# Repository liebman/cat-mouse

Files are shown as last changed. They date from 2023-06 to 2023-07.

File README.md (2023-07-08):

# Prototype Rover

Simple autonomous differential drive rover with LIDAR in RUST using an ESP32s3.

- [motor](motor) contains a simple PWM motor control for cheap brushed motors using a phase/enable type motor controller.
- [encoder](encoder) contains a PCNT based quadrature encoder controller to track the position of the encoder.
- [speed-control](speed-control) implements PID control of motor speed using encoder.
- [position-control](position-control) allows the motor position to be controlled by specifying the wanted position in degrees.
- [wheel](wheel) is an abstraction on top of position-control to specify motor position in millimeters.
- [differential-drive](differential-drive) implements rover rotation and forward/reverse movement by specifying the distance or rotation.
- [lidar](lidar) implements LIDAR with an inexpensive LD19 based Lidar like <https://www.amazon.com/dp/B0B1V8D36H>
- [rover](rover) runs around autonomously avoiding things.

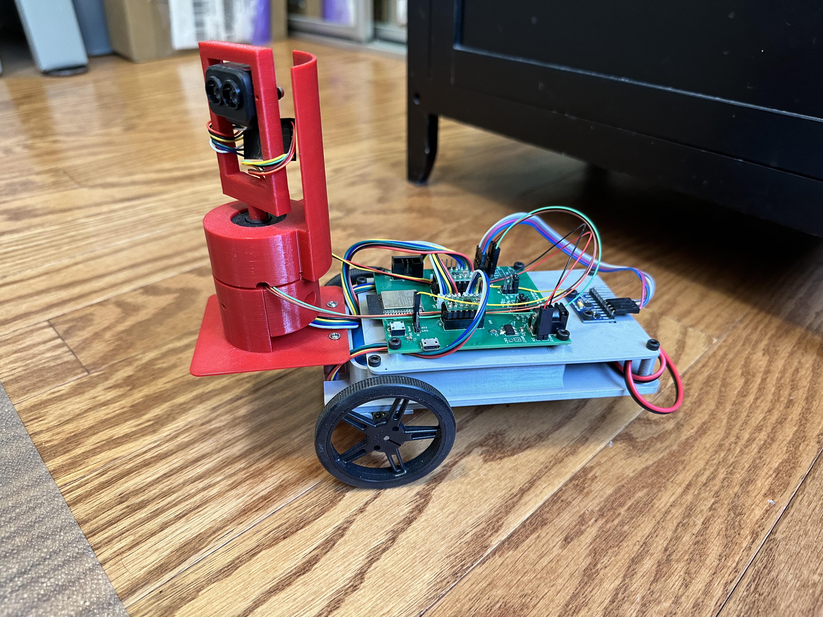
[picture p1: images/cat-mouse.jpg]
Cat Mouse


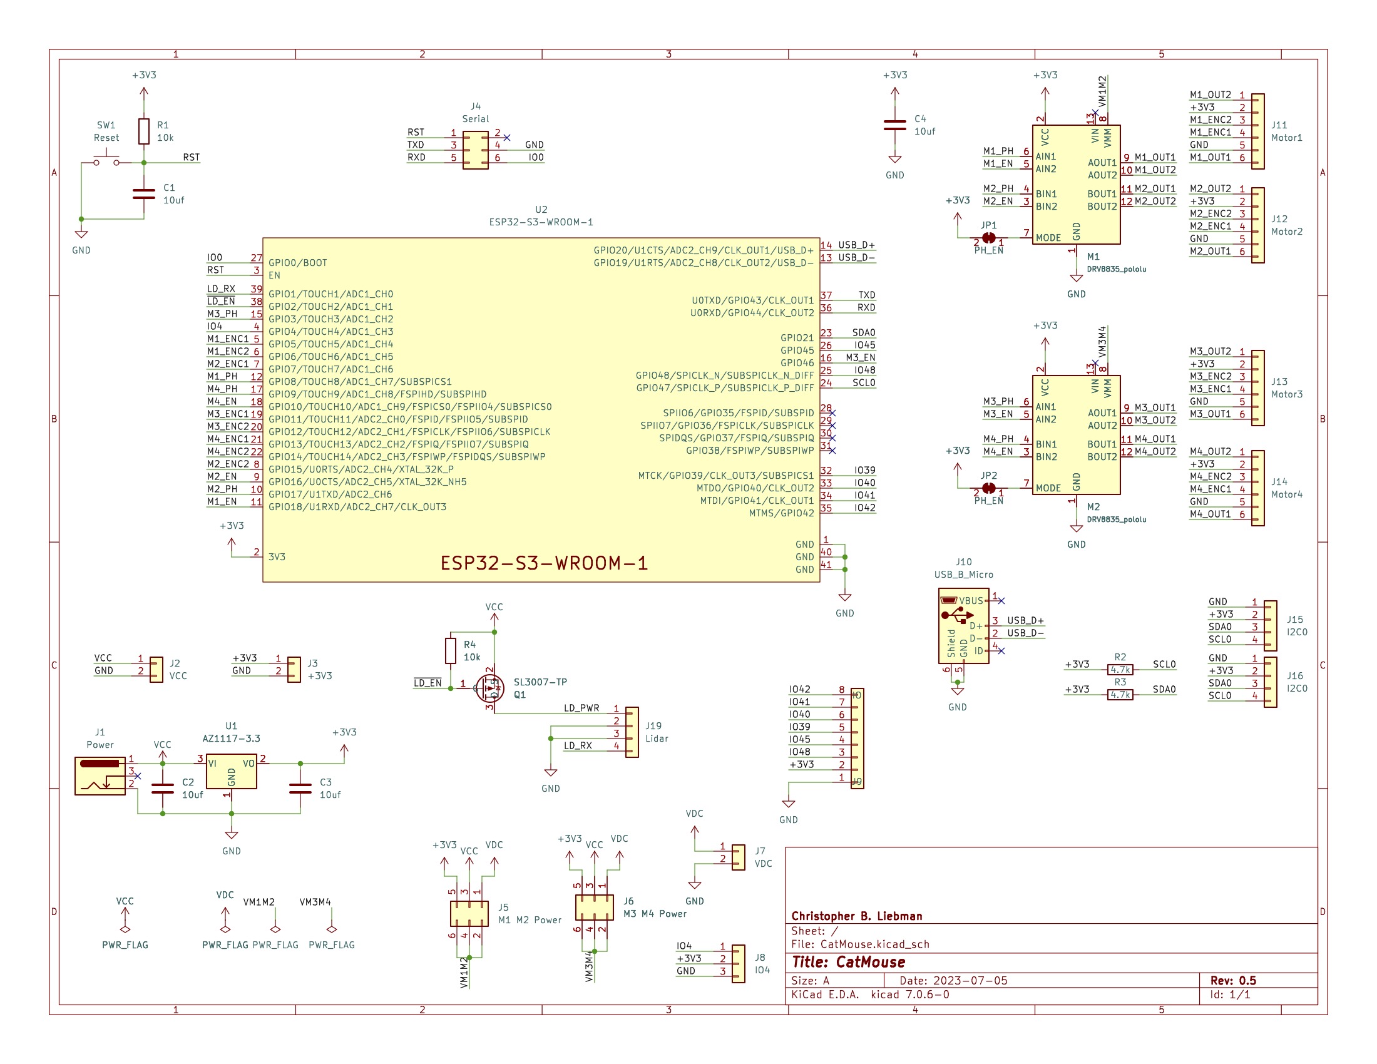
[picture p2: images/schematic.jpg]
Schematic


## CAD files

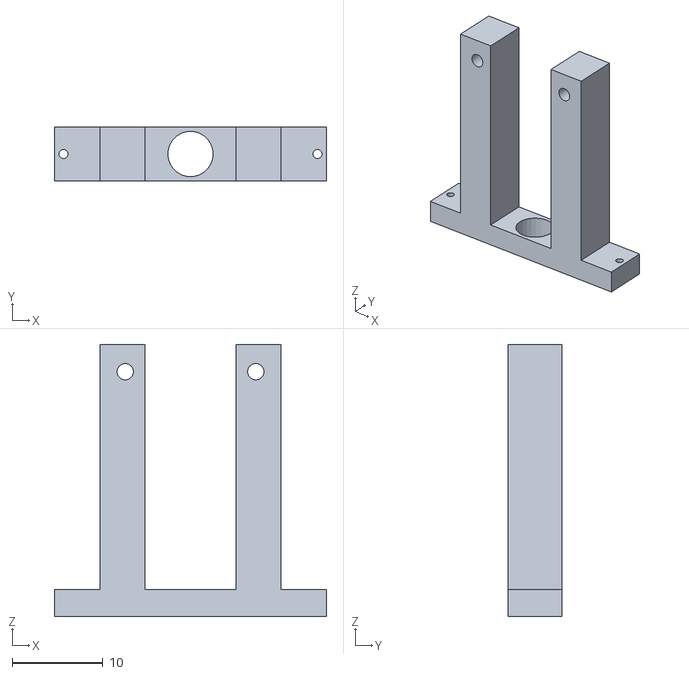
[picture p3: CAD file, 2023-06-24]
hardware/freecad/CatMouse-Lidar.stl
30.0 x 6.00 x 30.0

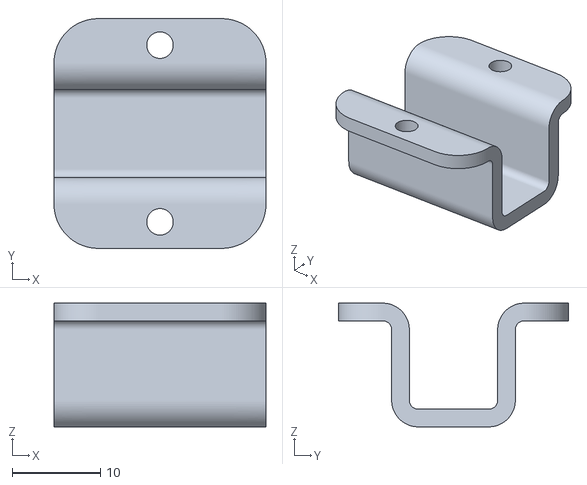
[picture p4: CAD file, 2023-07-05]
hardware/fusion360/N20Mount.stl
24.0 x 26.0 x 14.0

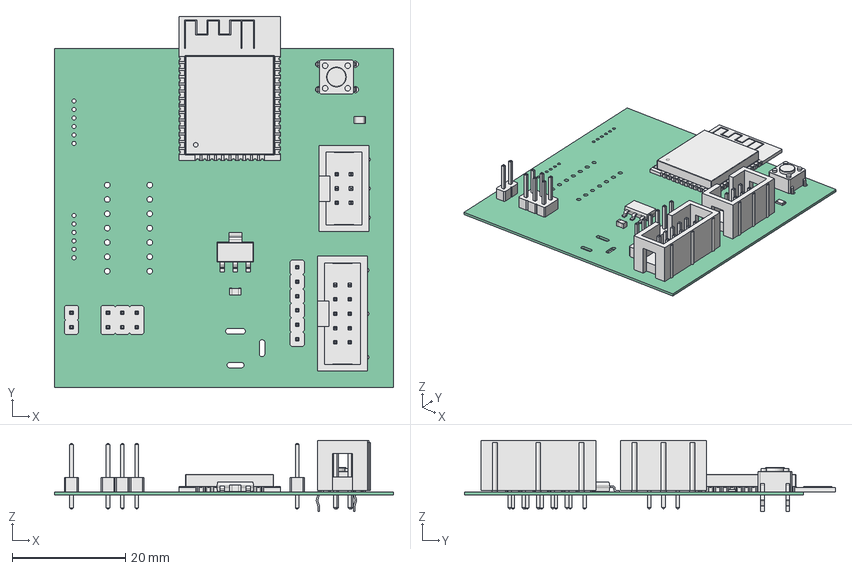
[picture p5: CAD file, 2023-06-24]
hardware/freecad/BoardOutline.FCStd
60.0 x 65.7 x 12.6 mm
Pcb_993c
U2_ESP32-WROOM-32_12fb92eafdae
C1_C_0805_2012Metric_3b40103215d8
R1_R_0805_2012Metric_3ca488a548dd
U1_SOT_223_f805ed2c4214
J3_IDC_Header_2x05_P254mm_Vertical_dc944acc4618
J2_IDC_Header_2x03_P254mm_Vertical_44bb01e61293
J4_PinHeader_2x03_P254mm_Vertical_54f72b17f13c
SW1_SW_PUSH_6mm_3bd36c4098d5
J8_PinHeader_1x06_P254mm_Vertical_c3c84403336c
J5_PinHeader_1x02_P254mm_Vertical_f570ed602196

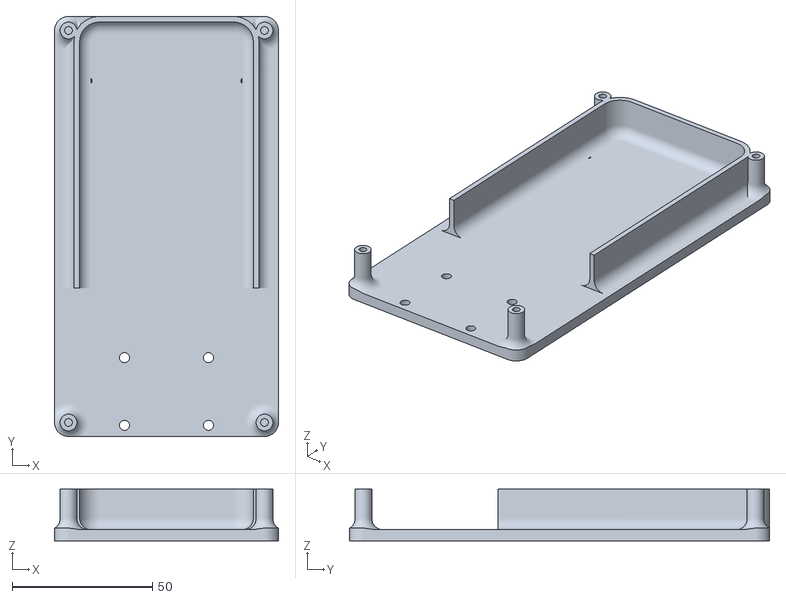
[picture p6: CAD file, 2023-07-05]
hardware/fusion360/Platform.stl
80.0 x 150.0 x 18.5

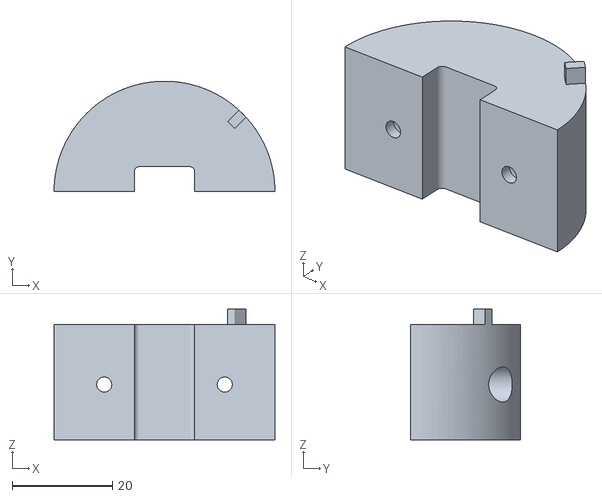
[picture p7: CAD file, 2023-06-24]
hardware/freecad/LIDAR-Front.stl
44.0 x 22.0 x 26.0

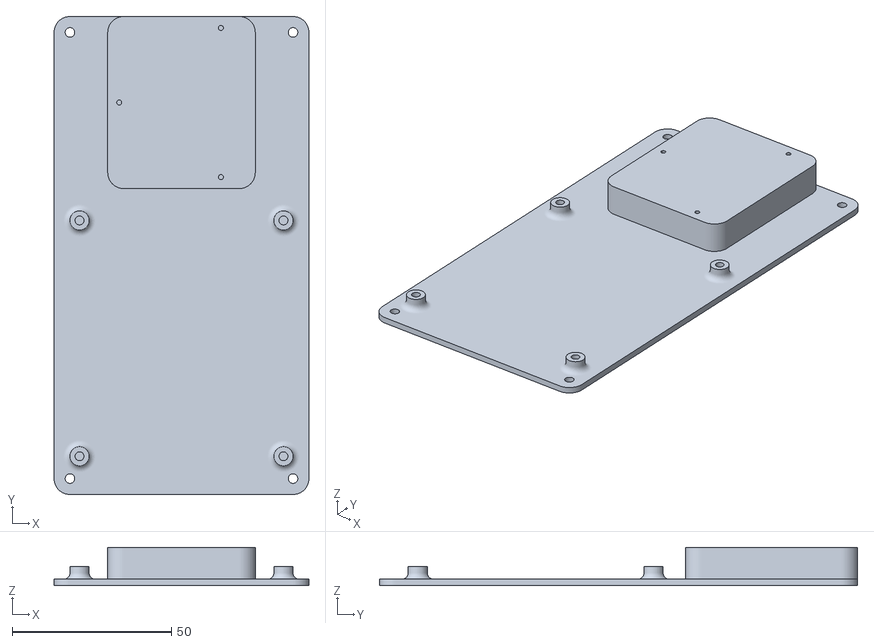
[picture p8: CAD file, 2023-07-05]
hardware/fusion360/BoardMount.stl
80.0 x 150.0 x 12.0

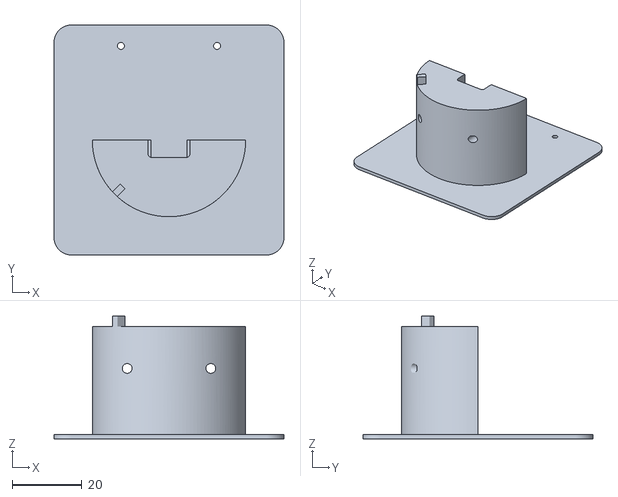
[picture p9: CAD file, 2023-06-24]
hardware/freecad/LIDAR-Back.stl
66.0 x 66.0 x 35.2

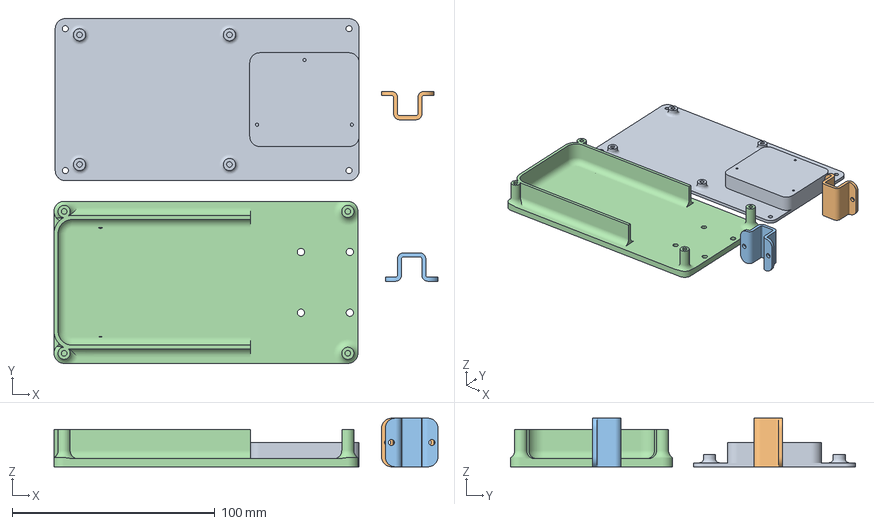
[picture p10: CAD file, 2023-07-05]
hardware/fusion360/cat-mouse.3mf
189.5 x 170.2 x 24.0 mm
BoardMount.stl
N20Mount.stl
Platform.stl

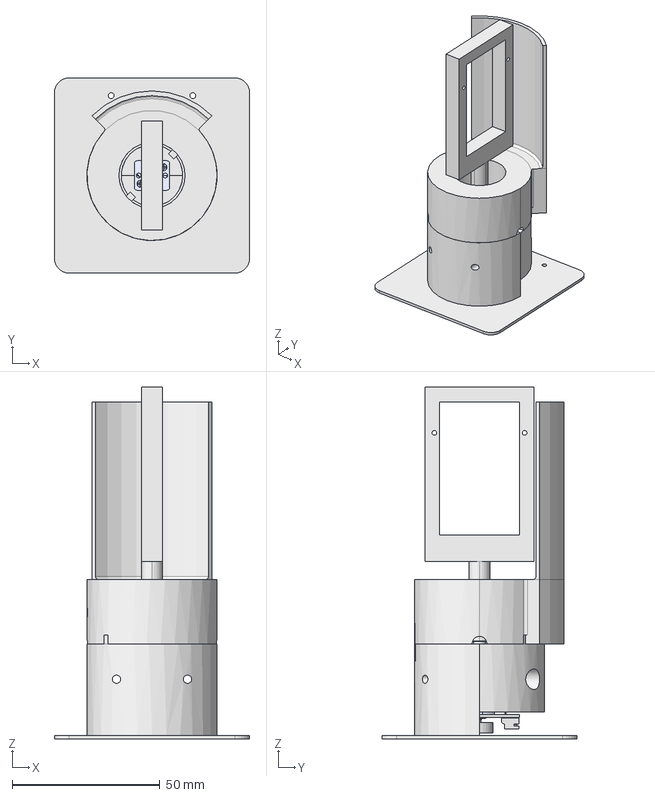
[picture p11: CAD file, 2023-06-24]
hardware/freecad/LIDAR.FCStd
66.0 x 66.0 x 119.0 mm
micro-metal-gearmotor-backshaft v1
S6B-ZR v1
Front
SlipRingTube
Back
TOFMount

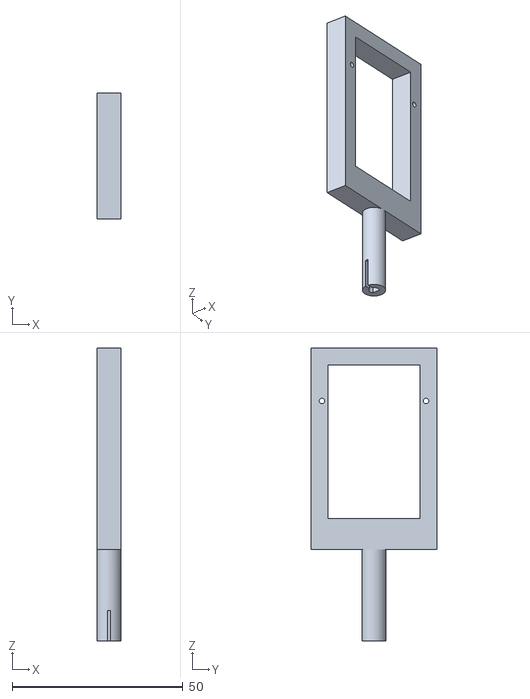
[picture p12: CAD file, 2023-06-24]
hardware/freecad/LIDAR-TOFMount.stl
7.00 x 37.0 x 85.8

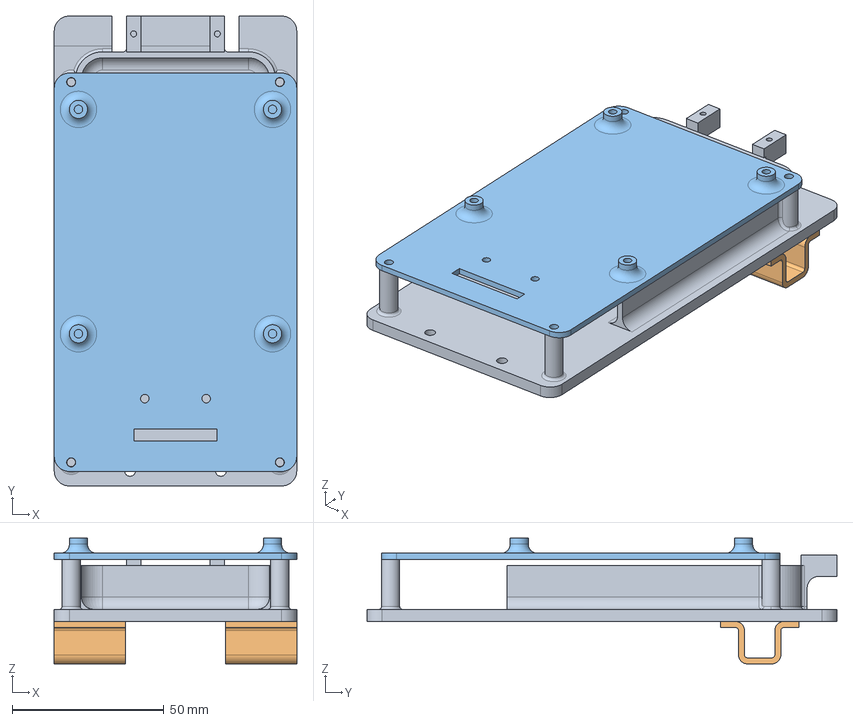
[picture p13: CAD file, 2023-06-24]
hardware/freecad/CatMouse.FCStd
80.0 x 155.0 x 41.5 mm
Platform
N20BracketV x 2
BoardPlatform

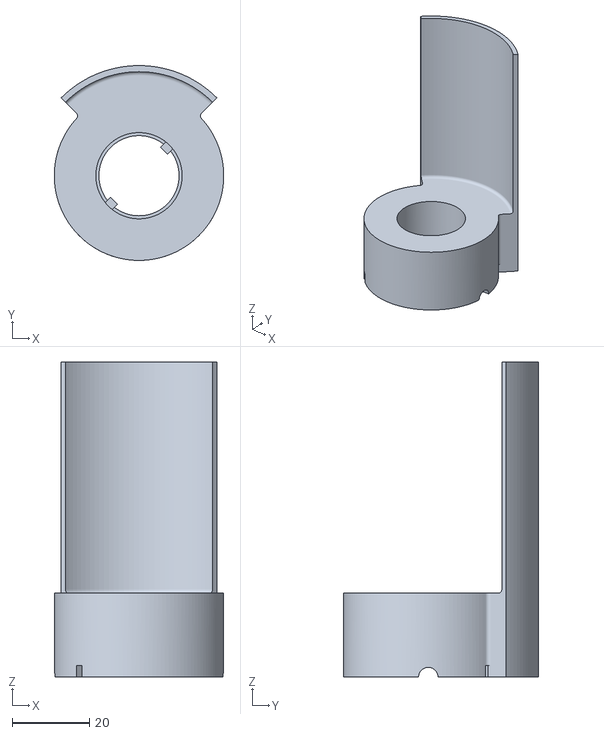
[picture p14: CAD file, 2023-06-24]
hardware/freecad/LIDAR-SlipRingTube.stl
44.0 x 50.6 x 81.8

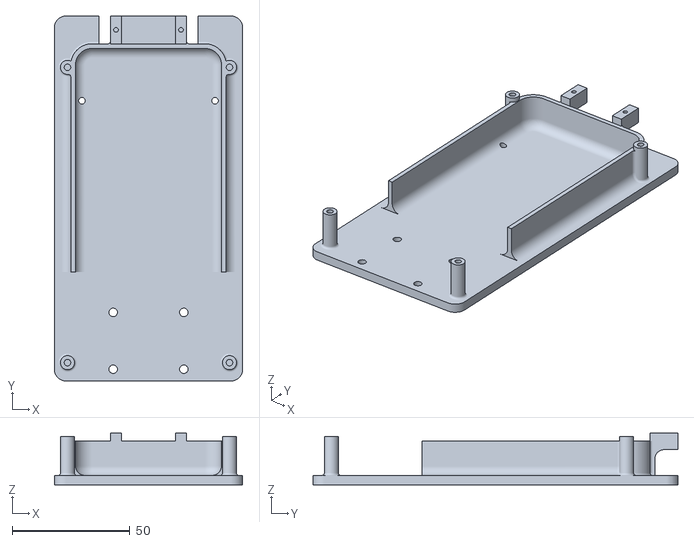
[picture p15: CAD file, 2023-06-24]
hardware/freecad/CatMouse-Platform.stl
80.0 x 155.0 x 21.9

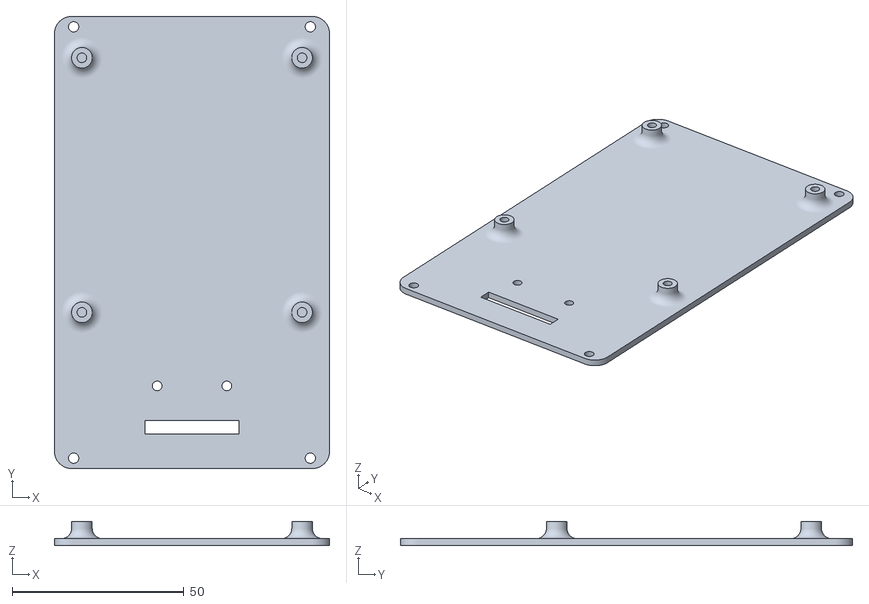
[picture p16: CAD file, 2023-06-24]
hardware/freecad/CatMouse-BoardPlatform.stl
80.0 x 131.4 x 7.00

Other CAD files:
hardware/freecad/CatMouse-N20BracketV.stl
hardware/fusion360/Rover-v23.f3z

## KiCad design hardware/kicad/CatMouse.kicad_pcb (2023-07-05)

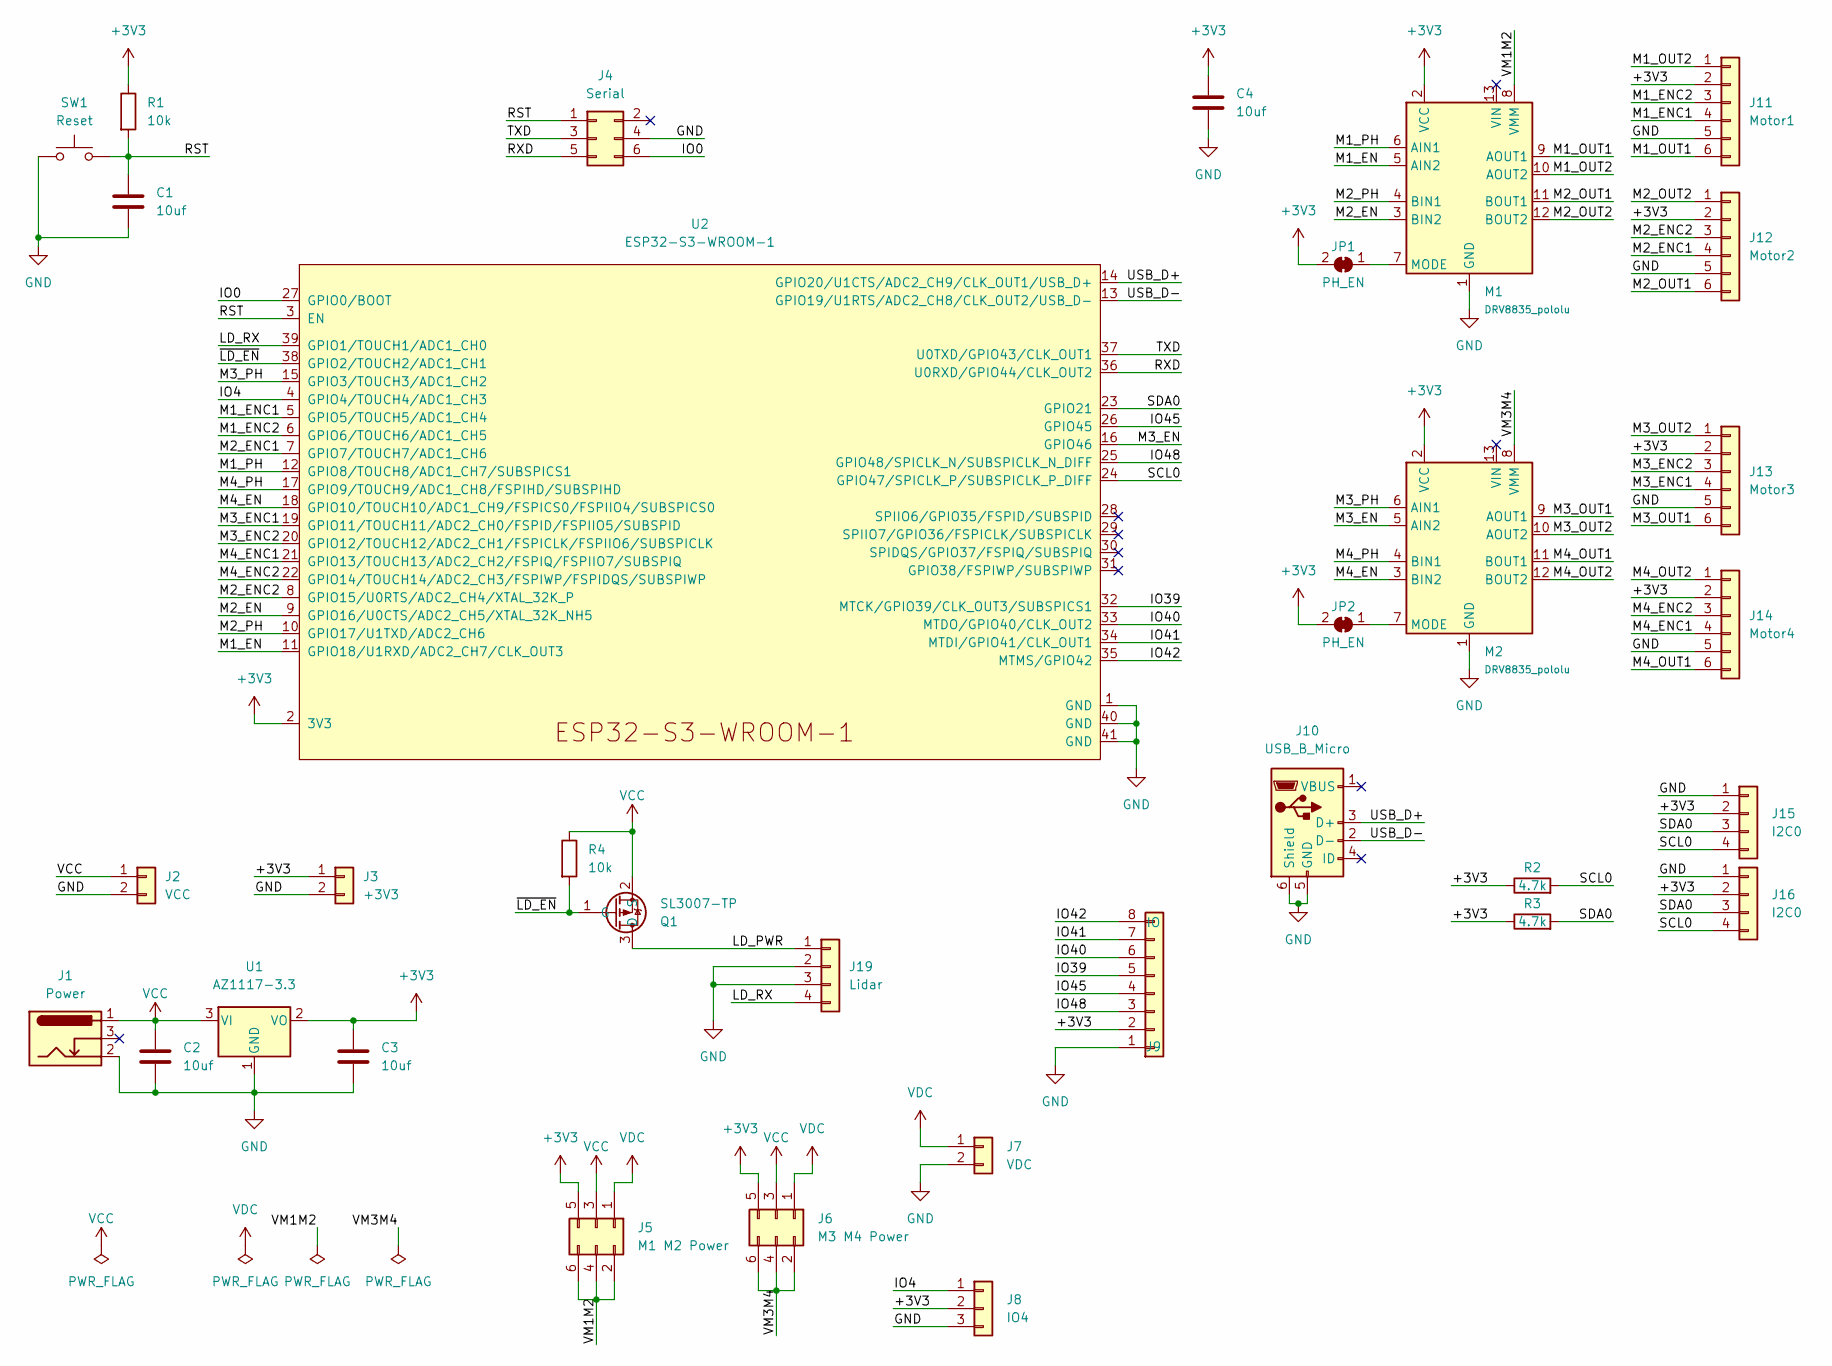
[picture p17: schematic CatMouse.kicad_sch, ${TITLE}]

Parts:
C1, C2, C3, C4: 10uf; C_0805_2012Metric_Pad1.18x1.45mm_HandSolder
J1: Power; BarrelJack_CUI_PJ-202A_Horizontal
J2: VCC; PinHeader_1x02_P2.54mm_Vertical
J3: +3V3; PinHeader_1x02_P2.54mm_Vertical
J4: Serial; IDC-Header_2x03_P2.54mm_Vertical
J5: M1 M2 Power; PinHeader_2x03_P2.54mm_Vertical
J6: M3 M4 Power; PinHeader_2x03_P2.54mm_Vertical
J7: VDC; PinHeader_1x02_P2.54mm_Vertical
J8: IO4; PinHeader_1x03_P2.54mm_Vertical
J9: IO; PinHeader_1x08_P2.54mm_Vertical
J10: USB_B_Micro; USB_Micro-B_GCT_USB3076-30-A
J11: Motor1; JST_ZH_B6B-ZR_1x06_P1.50mm_Vertical
J12: Motor2; JST_ZH_B6B-ZR_1x06_P1.50mm_Vertical
J13: Motor3; JST_ZH_B6B-ZR_1x06_P1.50mm_Vertical
J14: Motor4; JST_ZH_B6B-ZR_1x06_P1.50mm_Vertical
J15, J16: I2C0; PinHeader_1x04_P2.54mm_Vertical
J19: Lidar; JST_ZH_B4B-ZR_1x04_P1.50mm_Vertical
JP1, JP2: PH_EN; SolderJumper-2_P1.3mm_Bridged_RoundedPad1.0x1.5mm
M1, M2: DRV8835_pololu
Q1: SL3007-TP; SOT-23
R1, R4: 10k; R_0805_2012Metric_Pad1.20x1.40mm_HandSolder
R2, R3: 4.7k; R_0805_2012Metric_Pad1.20x1.40mm_HandSolder
SW1: Reset; SW_PUSH_6mm
U1: AZ1117-3.3; SOT-223-3_TabPin2
U2: ESP32-S3-WROOM-1

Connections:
+3V3: C3.1, C4.1, J3.1, J5.5, J6.5, J8.2, J9.2, J11.2, J12.2, J13.2, J14.2, J15.2, J16.2, JP1.2 (B), JP2.2 (B), M1.2 (VCC), M2.2 (VCC), R1.1, R2.1, R3.1, U1.2 (VO), U2.2 (3V3)
/IO0: J4.6, U2.27 (GPIO0/BOOT)
/IO4: J8.1, U2.4 (GPIO4/TOUCH4/ADC1_CH3)
/IO39: J9.5, U2.32 (MTCK/GPIO39/CLK_OUT3/SUBSPICS1)
/IO40: J9.6, U2.33 (MTDO/GPIO40/CLK_OUT2)
/IO41: J9.7, U2.34 (MTDI/GPIO41/CLK_OUT1)
/IO42: J9.8, U2.35 (MTMS/GPIO42)
/IO45: J9.4, U2.26 (GPIO45)
/IO48: J9.3, U2.25 (GPIO48/SPICLK_N/SUBSPICLK_N_DIFF)
/LD_PWR: J19.1, Q1.3 (D)
/LD_RX: J19.4, U2.39 (GPIO1/TOUCH1/ADC1_CH0)
/M1_EN: M1.5 (AIN2), U2.11 (GPIO18/U1RXD/ADC2_CH7/CLK_OUT3)
/M1_ENC1: J11.4, U2.5 (GPIO5/TOUCH5/ADC1_CH4)
/M1_ENC2: J11.3, U2.6 (GPIO6/TOUCH6/ADC1_CH5)
/M1_OUT1: J11.6, M1.9 (AOUT1)
/M1_OUT2: J11.1, M1.10 (AOUT2)
/M1_PH: M1.6 (AIN1), U2.12 (GPIO8/TOUCH8/ADC1_CH7/SUBSPICS1)
/M2_EN: M1.3 (BIN2), U2.9 (GPIO16/U0CTS/ADC2_CH5/XTAL_32K_NH5)
/M2_ENC1: J12.4, U2.7 (GPIO7/TOUCH7/ADC1_CH6)
/M2_ENC2: J12.3, U2.8 (GPIO15/U0RTS/ADC2_CH4/XTAL_32K_P)
/M2_OUT1: J12.6, M1.11 (BOUT1)
/M2_OUT2: J12.1, M1.12 (BOUT2)
/M2_PH: M1.4 (BIN1), U2.10 (GPIO17/U1TXD/ADC2_CH6)
/M3_EN: M2.5 (AIN2), U2.16 (GPIO46)
/M3_ENC1: J13.4, U2.19 (GPIO11/TOUCH11/ADC2_CH0/FSPID/FSPIIO5/S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)
/M3_ENC2: J13.3, U2.20 (GPIO12/TOUCH12/ADC2_CH1/FSPICLK/FSPIIO6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)
/M3_OUT1: J13.6, M2.9 (AOUT1)
/M3_OUT2: J13.1, M2.10 (AOUT2)
/M3_PH: M2.6 (AIN1), U2.15 (GPIO3/TOUCH3/ADC1_CH2)
/M4_EN: M2.3 (BIN2), U2.18 (GPIO10/TOUCH10/ADC1_CH9/FSPICS0/FSPIIO4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)
/M4_ENC1: J14.4, U2.21 (GPIO13/TOUCH13/ADC2_CH2/FSPIQ/FSPIIO7/S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)
/M4_ENC2: J14.3, U2.22 (GPIO14/TOUCH14/ADC2_CH3/FSPIWP/FSPIDQS/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)
/M4_OUT1: J14.6, M2.11 (BOUT1)
/M4_OUT2: J14.1, M2.12 (BOUT2)
/M4_PH: M2.4 (BIN1), U2.17 (GPIO9/TOUCH9/ADC1_CH8/FSPIHD/SUBSPIHD)
/RST: C1.1, J4.1, R1.2, SW1.2, U2.3 (EN)
/RXD: J4.5, U2.36 (U0RXD/GPIO44/CLK_OUT2)
/SCL0: J15.4, J16.4, R2.2, U2.24 (GPIO47/SPICLK_P/SUBSPICLK_P_DIFF)
/SDA0: J15.3, J16.3, R3.2, U2.23 (GPIO21)
/TXD: J4.3, U2.37 (U0TXD/GPIO43/CLK_OUT1)
/USB_D+: J10.3 (D+), U2.14 (GPIO20/U1CTS/ADC2_CH9/CLK_OUT1/USB_D+)
/USB_D-: J10.2 (D-), U2.13 (GPIO19/U1RTS/ADC2_CH8/CLK_OUT2/USB_D-)
/VM1M2: J5.2, J5.4, J5.6, M1.8 (VMM)
/VM3M4: J6.2, J6.4, J6.6, M2.8 (VMM)
/~LD_EN: Q1.1 (G), R4.2, U2.38 (GPIO2/TOUCH2/ADC1_CH1)
GND: C1.2, C2.2, C3.2, C4.2, J1.2, J2.2, J3.2, J4.4, J7.2, J8.3, J9.1, J10.5 (GND), J10.6 (Shield), J11.5, J12.5, J13.5, J14.5, J15.1, J16.1, J19.2, J19.3, M1.1 (GND), M1.14 (GND), M2.1 (GND), M2.14 (GND), SW1.1, U1.1 (GND), U2.1 (GND), U2.40 (GND), U2.41 (GND)
unnamed: JP1.1 (A), M1.7 (MODE)
unnamed: JP2.1 (A), M2.7 (MODE)
VCC: C2.1, J1.1, J2.1, J5.3, J6.3, Q1.2 (S), R4.1, U1.3 (VI)
VDC: J5.1, J6.1, J7.1

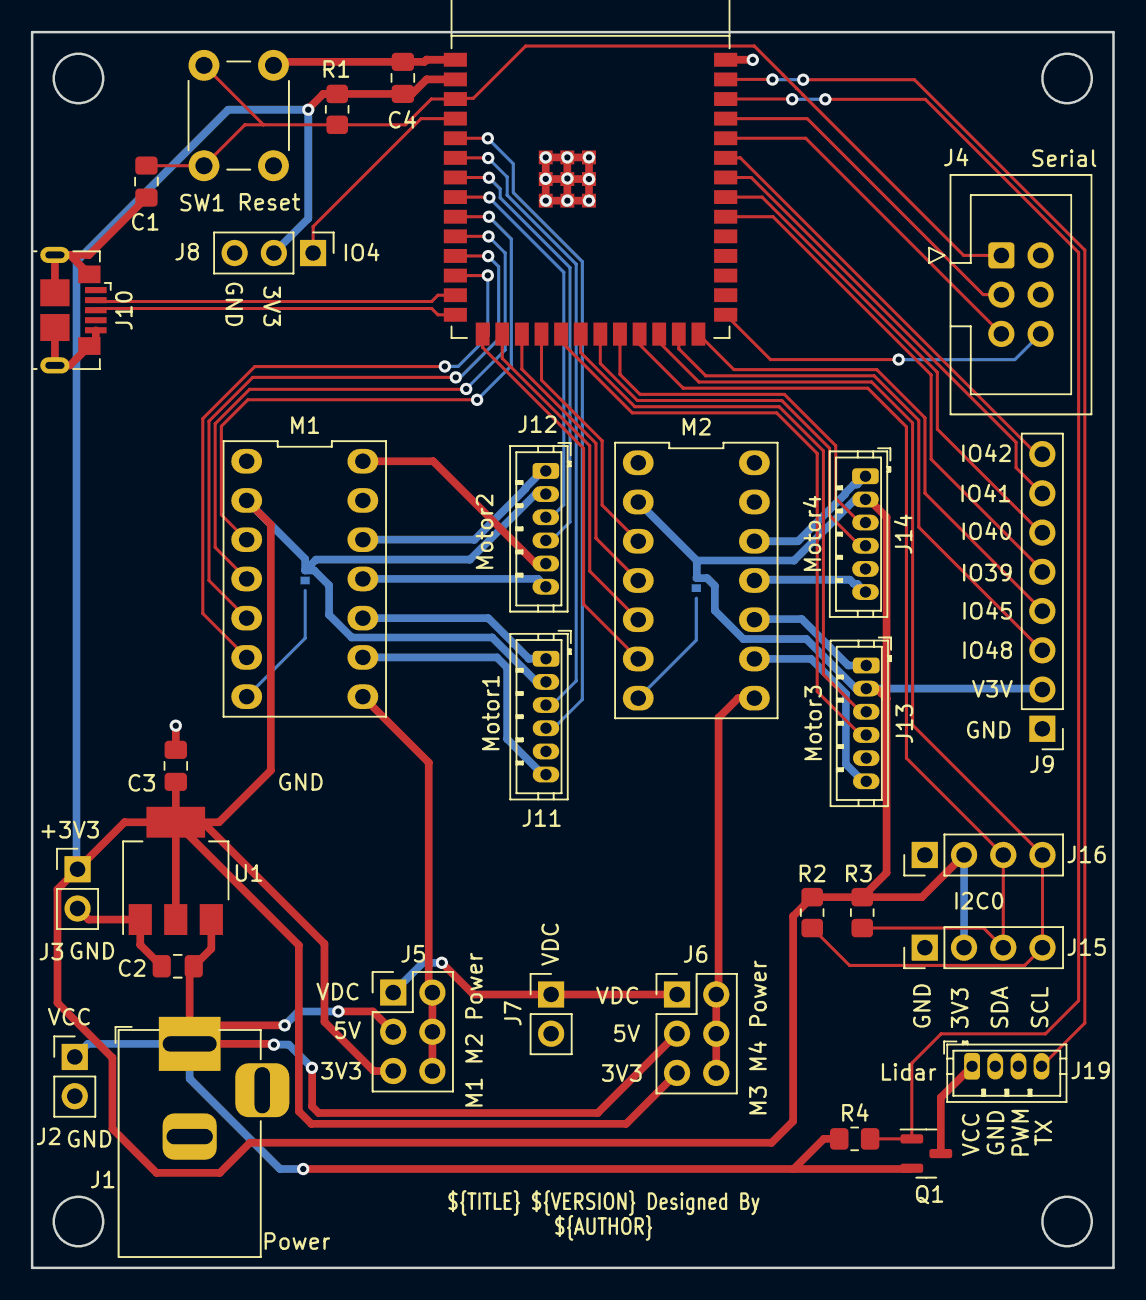
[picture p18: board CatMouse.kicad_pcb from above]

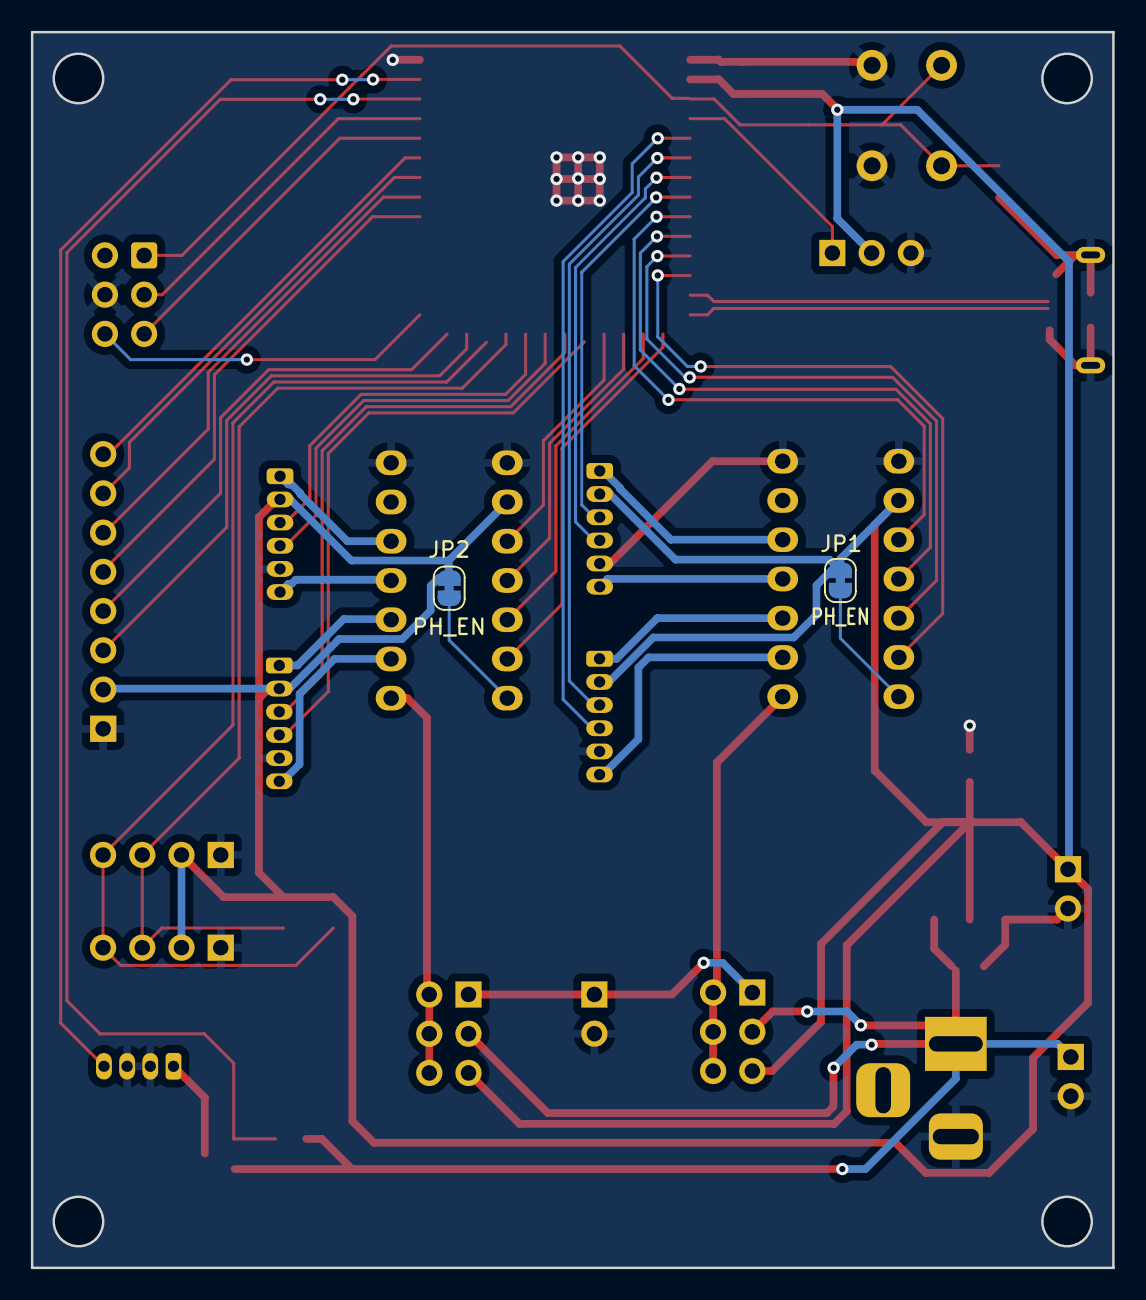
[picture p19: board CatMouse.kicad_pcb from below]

Board: 2 copper layers, 70.0 x 80.0 mm, 33 parts (2 on the bottom side), 50 nets.

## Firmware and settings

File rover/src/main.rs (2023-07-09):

use std::ffi::CStr;

use embedded_hal::delay::DelayUs;
use esp_idf_hal::delay::FreeRtos as delay;
use esp_idf_svc::eventloop::EspSystemEventLoop;
use esp_idf_svc::netif::IpEvent;
use esp_idf_svc::wifi::WifiEvent;
use esp_idf_sys::esp_vfs_spiffs_conf_t;
use esp_idf_sys::esp_vfs_spiffs_register;
use esp_idf_sys::{esp, EspError};

use log::*;

use crate::brain::Brain;
use crate::config::Config;
use crate::factory::MotorFactory;
use crate::http_controller::HttpController;
use crate::logger::Logger;
use crate::mqtt::Mqtt;
use crate::network::Network;
use crate::peripherals::SystemPeripherals;

mod brain;
mod config;
mod factory;
mod http_controller;
mod logger;
mod mqtt;
mod network;
mod peripherals;

fn log_compile_info() {
    esp_idf_sys::esp_app_desc!();

    // WARNING: Bug workaround: time & date are flipped!
    let date = unsafe { CStr::from_ptr(esp_app_desc.time.as_ptr()) }.to_string_lossy();
    let time = unsafe { CStr::from_ptr(esp_app_desc.date.as_ptr()) }.to_string_lossy();

    let name = unsafe { CStr::from_ptr(esp_app_desc.project_name.as_ptr()) }.to_string_lossy();
    let version = unsafe { CStr::from_ptr(esp_app_desc.version.as_ptr()) }.to_string_lossy();
    let idf = unsafe { CStr::from_ptr(esp_app_desc.idf_ver.as_ptr()) }.to_string_lossy();

    info!("Running {name} v{version} @ IDF v{idf} - compiled {date} {time}");
}

fn main() -> anyhow::Result<()> {
    esp_idf_sys::link_patches();
    Logger::initialize();
    log_compile_info();
    init_fs()?;
    let config = Config::new("/spiffs/config.json")?;

    info!("taking system peripherals");
    let peripherals = SystemPeripherals::take();

    info!("take the system event loop");
    let sysloop = EspSystemEventLoop::take()?;

    info!("setup network");
    let network = Network::new(
        peripherals.modem,
        sysloop.clone(),
        &config.wifi_ssid,
        &config.wifi_pass,
        &config.hostname,
    )?;

    // if wifi gets disconnected then reconnect.
    let _wifi_subs = {
        let network = network.clone();
        sysloop.subscribe(move |event: &WifiEvent| {
            info!("WIFI EVENT: {:+?}", event);
            #[allow(clippy::single_match)]
            match event {
                WifiEvent::StaDisconnected => {
                    network.connect().expect("start connection failed");
                }
                _ => {}
            }
        })?
    };

    let _ip_subs = sysloop.subscribe(|event: &IpEvent| {
        info!("IP EVENT: {:+?}", event);
        match event {
            IpEvent::ApStaIpAssigned(_) => {}
            IpEvent::DhcpIpAssigned(evt) => {
                info!("IP assigned: {}", evt.ip_settings.ip);
            }
            IpEvent::DhcpIp6Assigned(_) => {}
            IpEvent::DhcpIpDeassigned(_) => {}
        }
    })?;

    info!("setup MQTT");
    let mqtt = Mqtt::new(&config.mqtt_url, &config.mqtt_user, &config.mqtt_pass)?;
    Logger::set_mqtt(mqtt);

    // info!("setup i2c shared bus");
    // let i2c_config = I2cConfig::new().baudrate(400.kHz().into());
    // let i2c = shared_bus::new_std!(
    //     I2cDriver = I2cDriver::new(
    //         peripherals.i2c_unit,
    //         peripherals.i2c_pins.sda,
    //         peripherals.i2c_pins.scl,
    //         &i2c_config
    //     )?
    // )
    // .expect("failed to create i2c shared bus");

    info!("setup motor factory");
    let motor_factory = MotorFactory::new(peripherals.ledc_timer)?;

    info!("setup lidar");
    let lidar = factory::lidar(peripherals.lidar)?;

    info!("setup motor/encoder/speed/position: left");
    let motor = motor_factory.motor("left", peripherals.left_motor, false)?;
    let encoder = factory::encoder(peripherals.left_encoder, false)?;
    let speed = factory::speed(motor, encoder)?;
    let left = factory::positon(speed)?;

    info!("setup motor/encoder/speed/position: right");
    let motor = motor_factory.motor("right", peripherals.right_motor, true)?;
    let encoder = factory::encoder(peripherals.right_encoder, true)?;
    let speed = factory::speed(motor, encoder)?;
    let right = factory::positon(speed)?;

    info!("setup the differential drive");
    let drive = factory::drive(left, right)?;

    info!("setup brain");
    let brain = Brain::new(lidar, drive)?;

    let _http = HttpController::new(brain)?;
    info!("server is up!");

    loop {
        delay.delay_ms(1000);
    }
}

fn init_fs() -> Result<(), EspError> {
    info!("configuring SPIFFS");
    let spiffs_config = esp_vfs_spiffs_conf_t {
        base_path: "/spiffs\0".as_ptr() as *const i8,
        partition_label: std::ptr::null(),
        max_files: 5,
        format_if_mount_failed: false,
    };
    esp!(unsafe { esp_vfs_spiffs_register(&spiffs_config) })
}

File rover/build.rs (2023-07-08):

use esp_idf_part::PartitionTable;
use std::fs;
use std::io::Write;

use anyhow::Context;

// Necessary because of this issue: https://github.com/rust-lang/cargo/issues/9641
fn main() -> anyhow::Result<()> {
    embuild::build::CfgArgs::output_propagated("ESP_IDF")?;
    embuild::build::LinkArgs::output_propagated("ESP_IDF")?;
    make_flashfs_sh()
}

fn get_spiffs_size_and_address() -> Option<(u32, u32)> {
    let bin = fs::read("./partitions.csv").unwrap();
    let table = PartitionTable::try_from(bin).unwrap();
    for partition in table.partitions().iter() {
        if partition.name() == "spiffs" {
            return Some((partition.offset(), partition.size()));
        }
    }
    None
}

fn make_flashfs_sh() -> anyhow::Result<()> {
    let (address, size) = match get_spiffs_size_and_address() {
        Some(x) => x,
        None => {
            return Err(std::io::Error::new(
                std::io::ErrorKind::NotFound,
                "spiffs partition not found",
            )
            .into());
        }
    };

    let manifest_dir = std::env::var("CARGO_MANIFEST_DIR").context("CARGO_MANIFEST_DIR not set")?;
    let flashfs_var_path = format!("{manifest_dir}/flashfs.var");
    let mut flashfs_var = std::fs::OpenOptions::new()
        .create(true)
        .truncate(true)
        .write(true)
        .open(flashfs_var_path)?;
    writeln!(flashfs_var, "#!/bin/sh")?;
    writeln!(flashfs_var, "spiffs_size={size}")?;
    writeln!(flashfs_var, "spiffs_address=0x{address:0x}")?;
    Ok(())
}

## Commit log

2023-06-24 initial commit / functional rover
    [BoardOutline.FCStd, CatMouse-BoardPlatform.stl, CatMouse-Lidar.stl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]
2023-06-24 added schematic to readme
2023-06-30 board v0.4
    [CatMouse.kicad_pcb, CatMouse.kicad_sch]
2023-06-30 real 0.4
    [CatMouse.kicad_pcb]
2023-07-05 board 0.5 & fusion360 & stl files
    [BoardMount.stl, CatMouse.kicad_pcb, CatMouse.kicad_sch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]
2023-07-08 functional with new lidar
2023-07-08 update readme (still need to update schematic and image)
2023-07-08 update schematic
2023-07-09 update to current git (unreleased) esp-idf-{sys,hal,svc}
2023-07-14 update for new boards (v0.5)
2023-07-14 add left/right motor control to brain/http controler for testing
